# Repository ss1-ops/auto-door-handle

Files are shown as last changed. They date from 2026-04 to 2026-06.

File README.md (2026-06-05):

# OpenSesame — Motorized Apartment Door Handle

ESP32-S3 BLE actuator + SwiftUI iPhone app that pulls the door handle open on a tap. Fully 3D-printed mechanism with DC gear motor, limit switches, and closed-loop control. Daily driver on a real apartment door.

**Featured on [Sam Snyder's portfolio](https://ss1-ops.github.io#projects)** — see the Precision Mechatronics section.

## How It Works

1. Open the **OpenSesame** iPhone app (or trigger from lock screen / widget).
2. App scans for the BLE peripheral named `DoorOpener`.
3. Tap "Open" → writes the command `"OPEN"` to the BLE characteristic.
4. ESP32-S3 executes the full cycle:
   - Motor forward until `LIMIT_OPEN` triggers → stop.
   - Hold open for 2 seconds.
   - Motor reverse until `LIMIT_CLOSED` triggers → stop.
5. Firmware continuously notifies status (`Opening` / `Open` / `Closing` / `Closed`). App animates with glow effects and short video loops.
6. Handle returns to closed and ready state. Cycle is reliable and repeatable.

Serial console also accepts the literal string `OPEN` for testing.

## Hardware

| Component | Detail |
|---|---|
| MCU | ESP32-S3 |
| Motor Driver | L298N-style (IN1/IN2/ENA + PWM) |
| Motor | DC gear motor driving 3D-printed spur gear on the handle |
| Endstops | 2× normally-open limit switches (INPUT_PULLUP) |
| Indicator | 1× Adafruit NeoPixel (RGB) |
| Power | USB or wall adapter to door frame |
| Mechanism | 5-part 3D-printed assembly (see below) |

### Pin Assignments (ESP32-S3)

| Signal | Pin | Notes |
|---|-----|---|
| MOTOR_IN1 | 5 | Direction control |
| MOTOR_IN2 | 6 | Direction control |
| MOTOR_ENA | 7 | PWM enable (speed) |
| LIMIT_OPEN | 8 | Active LOW when handle fully open |
| LIMIT_CLOSED  | 9 | Active LOW when handle fully closed |
| RGB LED | 21  | NeoPixel data |

**Motor ramp**: Starts at PWM ~80 to overcome static friction, then ramps to full over ~180 ms. Prevents gear stripping on initial engagement.

## Firmware (ESP32-S3 + Arduino)

Key behaviors:
- BLE server with READ | WRITE | NOTIFY on a single characteristic.
- Device name: `DoorOpener`
- Service UUID: `4fafc201-1fb5-459e-8fcc-c5c9c331914b`
- Characteristic UUID: `beb5483e-36e1-4688-b7f5-ea07361b26a8`
- WiFi + ElegantOTA (wireless firmware updates at `http://<ip>/update` or mDNS `opensesame.local/update`).
- Status notifications on every state change.
- BLE advertising watchdog in the main loop (restarts advertising if it drops).
- Limit-switch homing with 10 s safety timeout.
- LED feedback: solid red (closed), green flash (opening), solid green (open), yellow flash (closing).

The firmware lives in `firmware/Door_Handle_BLE_Code/Door_Handle_BLE_Code.ino`.

## iOS App (SwiftUI)

- **OpenSesame** — native SwiftUI app using CoreBluetooth.
- Scans for and connects to `DoorOpener`.
- Single prominent action to send the open command.
- Real-time status text + color glow updates driven by BLE notifications.
- Bundled short video assets (`Door Opening.mov`, `Door Open.mov`, `Door Closing.mov`) for rich animated feedback (fixed-height player area so layout doesn't jump).
- Core Data persistence layer.
- Clean, minimal UI designed for quick one-tap use.

Project is in the `ios-app/OpenSesame/` directory (Xcode project).

## 3D-Printed Mechanical Parts

All parts were designed for easy FDM printing and apartment-door installation. The mechanism uses a toothed arc on the existing handle + spur gear on the motor shaft.

Files under `hardware/stl/` (GitHub renders these interactively in 3D — click any `.stl`):

- `Door Handle - Base Plate.stl`
- `Door Handle - Motor Mount Final.stl`
- `Door Handle - Motor Gear Final.stl`
- `Door Handle - Top Cover.stl`
- `Door Handle Toothed Arc.stl`

## Repo Structure

```
.
├── README.md
├── LICENSE
├── .gitignore
├── hardware/
│   └── stl/
│       └── Door Handle - *.stl     # 5 mechanical parts (view in 3D on GitHub)
├── firmware/
│   └── Door_Handle_BLE_Code/
│       └── Door_Handle_BLE_Code.ino   # ESP32-S3 Arduino firmware (BLE + OTA + motor)
└── ios-app/
    └── OpenSesame/                    # SwiftUI iPhone app (Xcode project + video assets)
```

## Building & Running

### Firmware
1. Open `firmware/Door_Handle_BLE_Code/Door_Handle_BLE_Code.ino` in Arduino IDE (or PlatformIO / Arduino CLI).
2. Select ESP32-S3 board, appropriate partition scheme (for OTA + BLE).
3. Update WiFi credentials if needed for your network (current: `WAVLINK-N`).
4. Flash over USB.
5. After first boot you can use ElegantOTA for future updates.

### iOS App
1. Open `ios-app/OpenSesame/OpenSesame.xcodeproj` in Xcode.
2. Select your iPhone target, sign with your developer account (requires BLE / Local Network capability).
3. Build & run. The app will request Bluetooth permission on first launch.

Test without the phone: connect via Serial Monitor and type `OPEN` + Enter.

## Daily Driver Reality

Installed on a real apartment door. Works from the lock screen via the app or Shortcuts integration potential. Limit switches provide reliable end-of-travel detection with no encoder needed. The 2-second hold gives enough time to enter before it auto-closes.

## Tech Stack & Skills Demonstrated

- Embedded: ESP32-S3 (FreeRTOS under the hood), Arduino/C++, BLE (GATT server + notify), WiFi + OTA
- Motor control: PWM ramping, limit switch homing, direction logic
- iOS: SwiftUI, CoreBluetooth, AVKit (video players), Core Data
- Mechanical: 3D printed custom mechanism design + integration with existing door hardware
- End-to-end ownership: firmware ↔ BLE protocol ↔ phone UX ↔ physical mechanism

## License

MIT License — see [LICENSE](LICENSE).

---

**Sam Snyder** — Robotics / Automation / Precision Mechatronics  
Austin, TX | [samhsnyder.com](https://samhsnyder.com) | [Portfolio](https://ss1-ops.github.io)

This is a complete, ship-it personal project showing firmware + app + mechanism integration under real-world constraints.

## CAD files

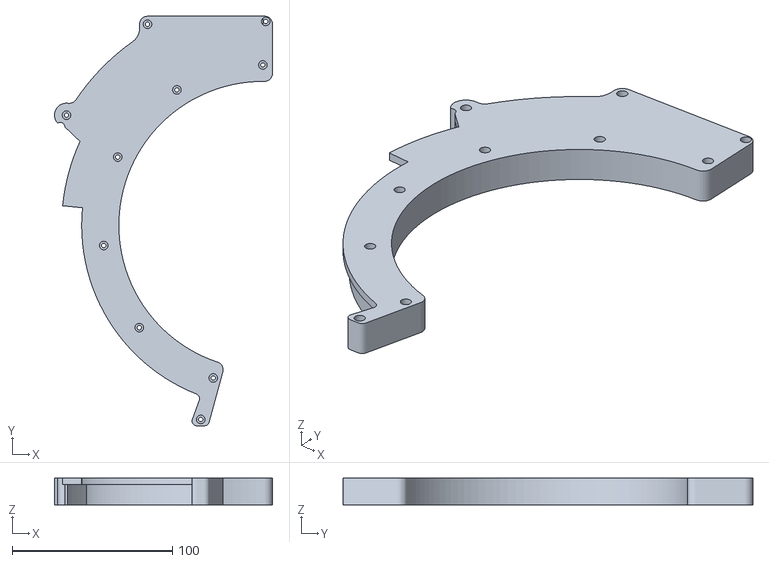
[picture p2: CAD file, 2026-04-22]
hardware/stl/Door Handle - Top Cover.stl
136.2 x 256.0 x 16.6

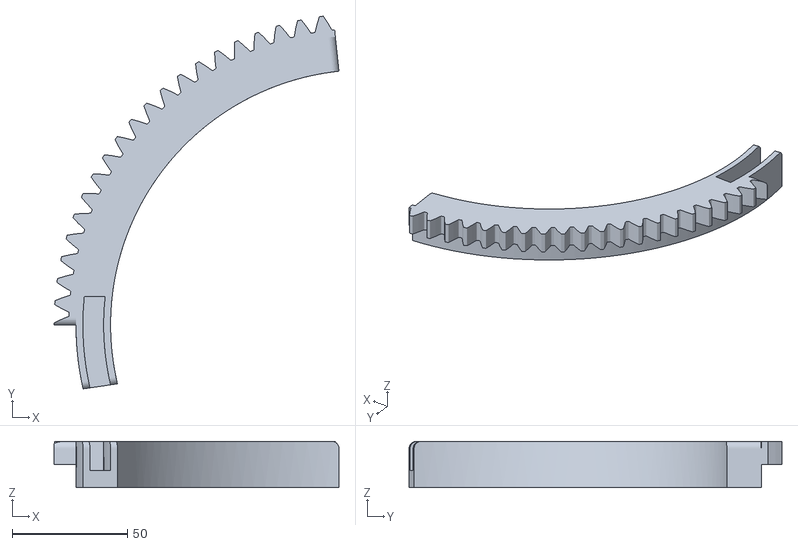
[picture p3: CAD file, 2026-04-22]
hardware/stl/Door Handle Toothed Arc.stl
123.4 x 161.5 x 20.0

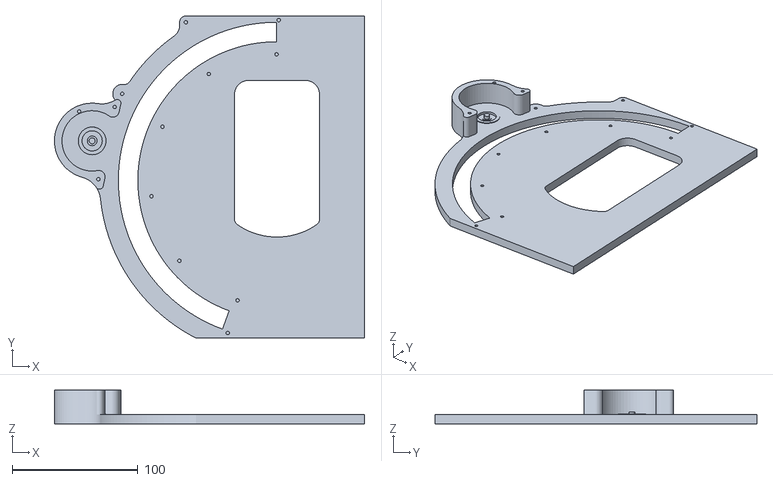
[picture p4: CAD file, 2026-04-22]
hardware/stl/Door Handle - Base Plate.stl
246.6 x 256.0 x 27.0

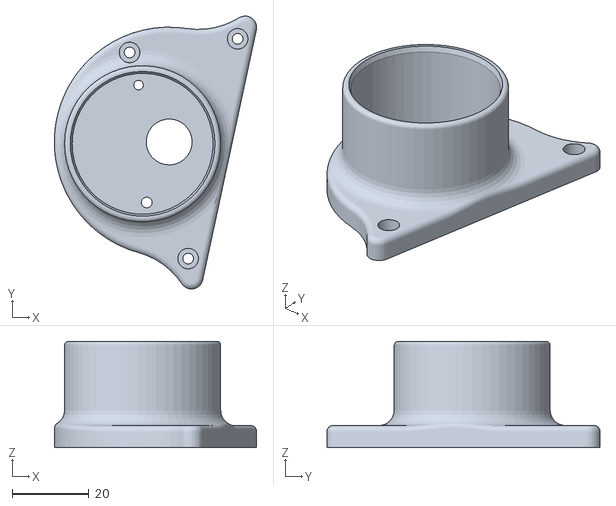
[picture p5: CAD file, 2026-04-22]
hardware/stl/Door Handle - Motor Mount Final.stl
52.8 x 71.3 x 27.8

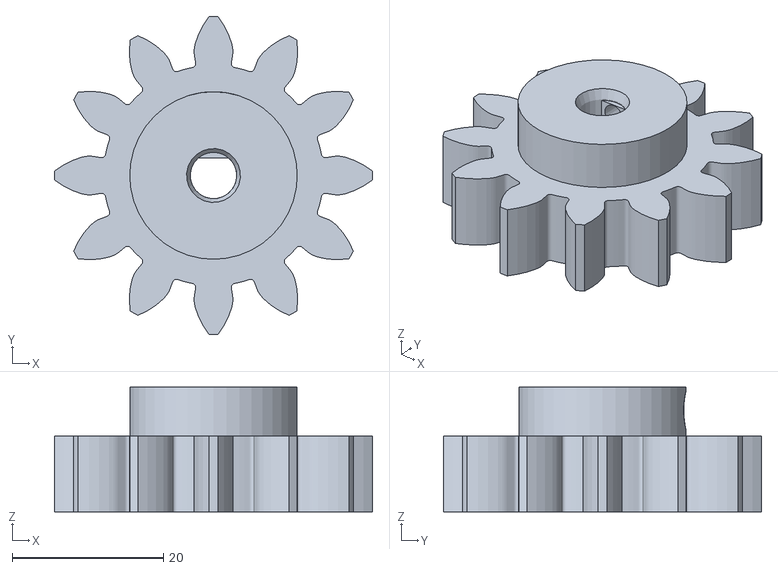
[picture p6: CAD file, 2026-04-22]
hardware/stl/Door Handle - Motor Gear Final.stl
42.0 x 42.0 x 16.5

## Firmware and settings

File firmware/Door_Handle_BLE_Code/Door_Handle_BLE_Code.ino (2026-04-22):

#include <BLEDevice.h>
#include <BLEUtils.h>
#include <BLEServer.h>
#include <Adafruit_NeoPixel.h>
#include <WiFi.h>
#include <WebServer.h>
#include <ElegantOTA.h>

// ================== PIN DEFINITIONS ==================
const int MOTOR_IN1     = 5;
const int MOTOR_IN2     = 6;
const int MOTOR_ENA     = 7;

const int LIMIT_OPEN    = 8;
const int LIMIT_CLOSED  = 9;

#define RGB_PIN     21
#define NUM_PIXELS  1

Adafruit_NeoPixel pixel(NUM_PIXELS, RGB_PIN, NEO_RGB + NEO_KHZ800);

// ================== WiFi & OTA ==================
const char* ssid = "WAVLINK-N";
const char* password = "Jk12345678";

WebServer server(80);

// ================== BLE DEFINITIONS ==================
#define SERVICE_UUID        "4fafc201-1fb5-459e-8fcc-c5c9c331914b"
#define CHARACTERISTIC_UUID "beb5483e-36e1-4688-b7f5-ea07361b26a8"

BLECharacteristic *pCharacteristic;

// ================== LED HELPERS ==================
void setRed()    { pixel.setPixelColor(0, pixel.Color(255, 0, 0)); pixel.show(); }
void setGreen()  { pixel.setPixelColor(0, pixel.Color(0, 255, 0)); pixel.show(); }
void setYellow() { pixel.setPixelColor(0, pixel.Color(255, 180, 0)); pixel.show(); }

void flashGreen(int times = 1) {
  for (int i = 0; i < times; i++) {
    setGreen(); delay(180); pixel.setPixelColor(0, 0); pixel.show(); delay(180);
  }
}

void flashYellow(int times = 1) {
  for (int i = 0; i < times; i++) {
    setYellow(); delay(200); pixel.setPixelColor(0, 0); pixel.show(); delay(200);
  }
}

void sendStatus(const char* status) {
  if (pCharacteristic) {
    pCharacteristic->setValue(status);
    pCharacteristic->notify();
    Serial.print("Sent status: ");
    Serial.println(status);
  }
}

// ================== MOTOR HELPERS ==================
void motorForward() { digitalWrite(MOTOR_IN1, HIGH); digitalWrite(MOTOR_IN2, LOW);  digitalWrite(MOTOR_ENA, HIGH); }
void motorReverse() { digitalWrite(MOTOR_IN1, LOW);  digitalWrite(MOTOR_IN2, HIGH); digitalWrite(MOTOR_ENA, HIGH); }
void motorStop()    { digitalWrite(MOTOR_IN1, LOW);  digitalWrite(MOTOR_IN2, LOW);  digitalWrite(MOTOR_ENA, LOW); }

// ================== DOOR CYCLE ==================
void runDoorCycle() {
  sendStatus("Opening");
  motorForward();
  unsigned long startTime = millis();
  while (digitalRead(LIMIT_OPEN) == HIGH) {
    flashGreen(1);
    if (millis() - startTime > 10000) break;
  }
  motorStop();

  sendStatus("Open");
  setGreen();
  delay(2000);

  sendStatus("Closing");
  motorReverse();
  startTime = millis();
  while (digitalRead(LIMIT_CLOSED) == HIGH) {
    flashYellow(1);
    if (millis() - startTime > 10000) break;
  }
  motorStop();

  sendStatus("Closed");
  setRed();
  Serial.println("Cycle complete");
}

// ================== BLE CALLBACK ==================
class MyCallbacks: public BLECharacteristicCallbacks {
    void onWrite(BLECharacteristic *pChar) {
      String value = pChar->getValue();
      if (value == "OPEN") {
        Serial.println("OPEN received from iPhone");
        runDoorCycle();
      }
    }
};

void setup() {
  Serial.begin(115200);
  delay(1000);

  // Pin setup
  pinMode(MOTOR_IN1, OUTPUT);
  pinMode(MOTOR_IN2, OUTPUT);
  pinMode(MOTOR_ENA, OUTPUT);
  pinMode(LIMIT_OPEN, INPUT_PULLUP);
  pinMode(LIMIT_CLOSED, INPUT_PULLUP);
  motorStop();

  // RGB LED
  pixel.begin();
  pixel.setBrightness(130);
  setRed();

  // ================== WiFi + OTA ==================
  WiFi.mode(WIFI_STA);
  WiFi.begin(ssid, password);
  Serial.print("Connecting to WiFi");
  while (WiFi.status() != WL_CONNECTED) {
    delay(500);
    Serial.print(".");
  }
  Serial.println("\nWiFi connected!");
  Serial.print("IP: http://");
  Serial.println(WiFi.localIP());

  ElegantOTA.begin(&server);
  server.begin();
  Serial.println("OTA ready → http://" + WiFi.localIP().toString() + "/update");

  // ================== BLE Setup ==================
  BLEDevice::init("DoorOpener");

  BLEServer *pServer = BLEDevice::createServer();
  BLEService *pService = pServer->createService(SERVICE_UUID);

  pCharacteristic = pService->createCharacteristic(
                      CHARACTERISTIC_UUID,
                      BLECharacteristic::PROPERTY_READ |
                      BLECharacteristic::PROPERTY_WRITE |
                      BLECharacteristic::PROPERTY_NOTIFY);

  pCharacteristic->setCallbacks(new MyCallbacks());
  pCharacteristic->setValue("Closed");

  pService->start();

  BLEAdvertising *pAdvertising = BLEDevice::getAdvertising();
  pAdvertising->addServiceUUID(SERVICE_UUID);
  pAdvertising->setScanResponse(true);
  BLEDevice::startAdvertising();

  sendStatus("Closed");

  Serial.println("=== Door Opener Ready (BLE + OTA + Advertising Fix) ===");
}

void loop() {
  server.handleClient();
  ElegantOTA.loop();

  // CRITICAL: Keep BLE advertising alive
  if (!BLEDevice::getAdvertising()->isAdvertising()) {
    Serial.println("Advertising stopped - restarting...");
    BLEDevice::getAdvertising()->start();
  }

  if (Serial.available()) {
    String input = Serial.readStringUntil('\n');
    input.trim();
    if (input == "OPEN") {
      runDoorCycle();
    }
  }
  delay(10);
}

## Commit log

2026-04-22 Initial commit: BLE door handle firmware, iOS app, and STL files
    [Door Handle - Base Plate.stl, Door Handle - Motor Gear Final.stl, Door Handle - Motor Mount Final.stl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]
2026-06-05 docs: add comprehensive README + MIT license for portfolio visibility
    - Full end-to-end description matching the site pitch (ESP32-S3 + BLE + SwiftUI iPhone app + 3D-printed mechanism)
    - Hardware pin table, component list, and motor ramp details from actual firmware
    - BLE UUIDs, status protocol, OTA instructions, and cycle logic
    - iOS app architecture notes (BLEManager, video-backed animations, glow UI)
    - 3D STL listing with note on GitHub interactive viewer
    - Tech stack summary and "daily driver" reality callout
    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
2026-06-05 chore: reorganize into hardware/firmware/ios-app for cleaner first impression
    - Move 5 STL files into hardware/stl/
    - Move firmware into firmware/
    - Move iOS project into ios-app/
    - Update README structure diagram and paths to match
    This makes the GitHub repo tree look intentional and professional when visitors arrive from the portfolio.
    [Door Handle - Base Plate.stl, Door Handle - Motor Gear Final.stl, Door Handle - Motor Mount Final.stl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]
2026-06-05 fix: move last stray STL
    [Door Handle Toothed Arc.stl]
